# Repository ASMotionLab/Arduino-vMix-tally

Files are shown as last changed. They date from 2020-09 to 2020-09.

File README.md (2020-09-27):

# Arduino vMix tally

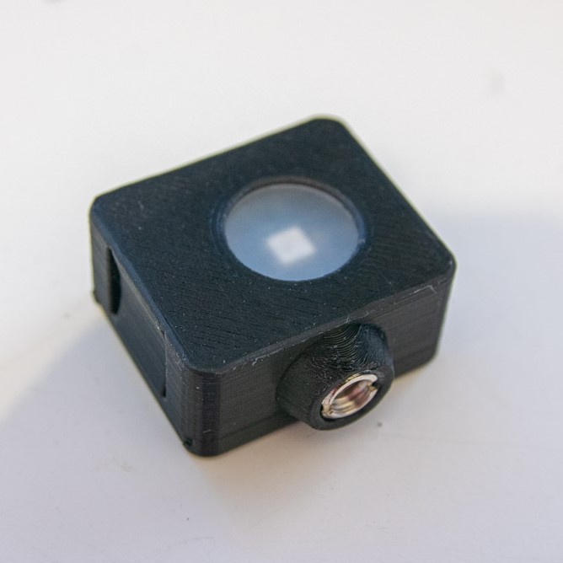
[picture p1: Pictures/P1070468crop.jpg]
Image of Tally


This project contains the firmware for a tally system based on an Arduino esp8266 and the vMix TCP API. 
Pictures of the tally can be found in the Pictures folder.

This fork adapts the existing project by Thomas Mout to work with a single WS2812B (Neopixel) led shield instead of the original LED matrix shield. Multiple WS2812B leds will also work.

There are modifications to change LED brightness from the setup web page, and a factory reset button to load defaults.

Also added is a checkbox for enabling/disabling the green colour (the Preview colour of vMix).
This indicator may not be wanted if pointing tallys at the talent.

The enclosure has also been redesigned to fit the dev board + shield, to retain it, to allow mounting to a 1/4 tripod screw via a 3/8 adaptor boss.

## Installation

### Hardware

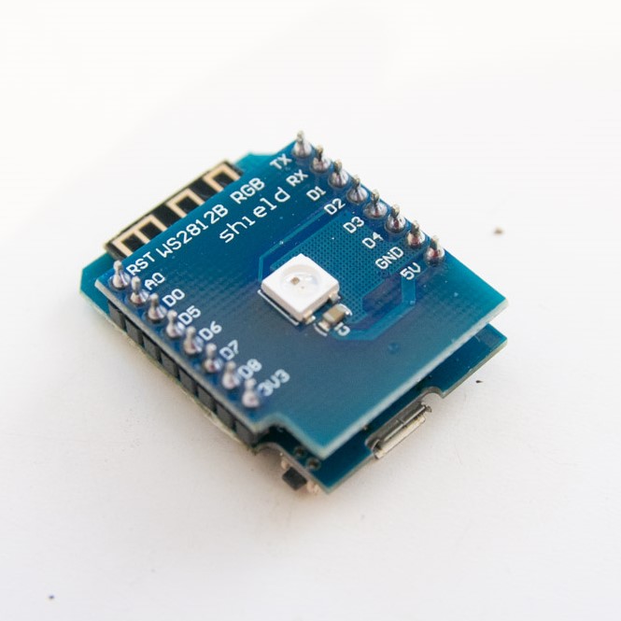
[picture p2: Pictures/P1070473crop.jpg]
Image of shield


This fork uses a WeMos/Lolin D1 Mini clone
https://www.banggood.com/Geekcreit-D1-mini-V2_2_0-WIFI-Internet-Development-Board-Based-ESP8266-4MB-FLASH-ESP-12S-Chip-p-1143874.html

and a WS2812B (Neopixel) shield.
https://www.amazon.co.uk/ILS-WS2812B-RGB-Shield-Mini/dp/B079128452

The 2 are soldered together, leaving clearance the thickness of a stanley blade between the D1 mini and the shield.

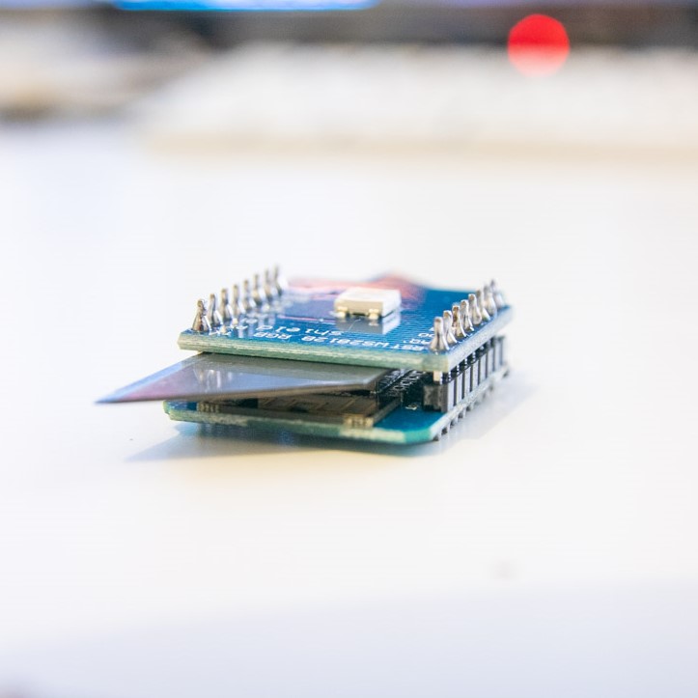
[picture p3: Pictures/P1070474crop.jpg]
Image of clearance


The 3d printable enclosure is designed to retain this board sandwich with a tight tolerance.

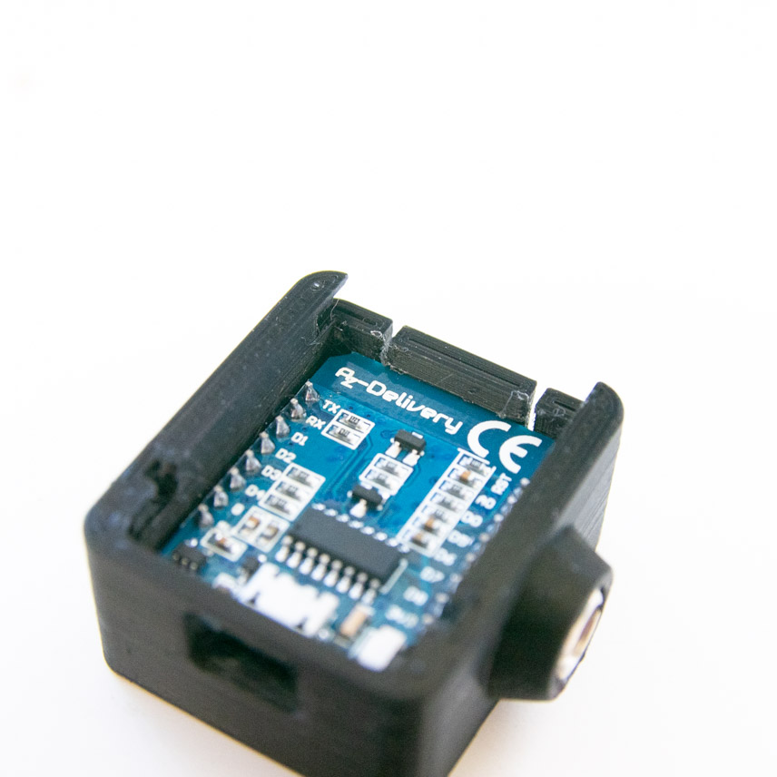
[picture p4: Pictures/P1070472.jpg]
Image of retention


The 'lens' used to diffuse the led is a 2cm diameter frosted acrylic circle (3mm thickness). It should press into the case if your printer is accurately calibrated.

#### Solder instructions

Make sure to match the board orientation when soldering the D1 and shield - make sure 3v3 goes to 3v3, 5v to 5v, etc etc.

### Software

#### 1. Install Arduino IDE

Download the Arduino IDE from the [Arduino website](https://www.arduino.cc/en/main/software) and install it.  
After the installation is complete go to File > Preferences and add http://arduino.esp8266.com/stable/package_esp8266com_index.json to the additional Board Manager URL.
Go to Tools > Board > Board Manager, search for *esp8266* and install the latest version.
After the installation go to Tools > Board and select *Wemos D1 R2* as your default board.  

#### 2. Copy libraries

All libraries included in the Libaries folder are required for this project. Please copy them to your own Arduino libraries folder (default path: *user/documents/Arduino/libraries*).
If some components are missing, you can easily find what's missing by googling the error.

#### 3. Uploading static files

Connect the Arduino to the computer with a USB cable.  
The static files in the Arduino-vMix-Tally/data folder must be uploaded using the Tools > ESP8266 Sketch Data Upload in the Arduino IDE.  

#### 4. Uploading firmware

Upload the Arduino-vMix-Tally/Arduino-vMix-Tally.ino from this repository to the D1 mini

#### 5. Connecting to your wireless network

To start with, the tally will try to connect to a non existent wifi network and will fail. After it fails, it becomes a wifi access point.
You can connect directly to it. It'll be called "vMix_Tally_X" where X is a number. The WiFi password is the same name, with "_access" added to the end._
So If the Access Point name is vMix_Tally_255, the password will be vMix_Tally_255_access.

Once you connect to it, navigate to address 192.168.4.1 in the browser.
You may find that there are strange characters in the entry fields. This is because the memory locations where this data are stored on the D1 may not be clear.
You can do a factory reset and come back to the page, or just delete all the strangeness and set up the fields to suit your network.

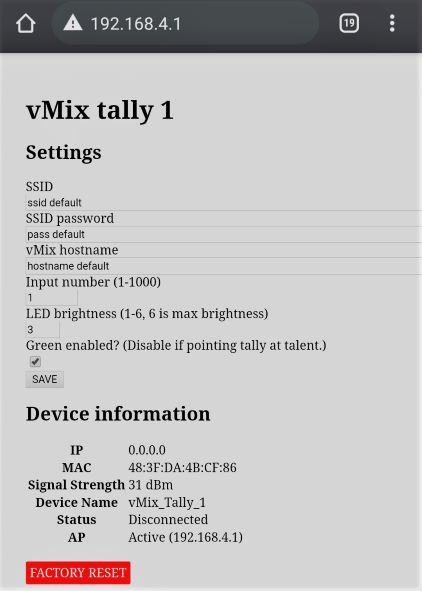
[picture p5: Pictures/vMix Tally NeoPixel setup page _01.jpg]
Image of ap setup


Hit Save. Tally restarts.

#### 5. Connecting to vMix

If all the details are right and vMix is running, it should light up blue and after 5-30s either turn off, go green or red.
vMix API runs on port 8099, so this port needs to be reachable by the tally - make sure firewall isn't blocking it.

#### 6. Colours

BLUE light indicates the tally is trying to connect to a network, or it's an Access Point of it's own.

OFF means the camera is not being previewed and it's not live (but vMix connection is working).

GREEN means the camera is being previewed (vMix connection is working).

RED means the camera is LIVE (vMix connection is working).

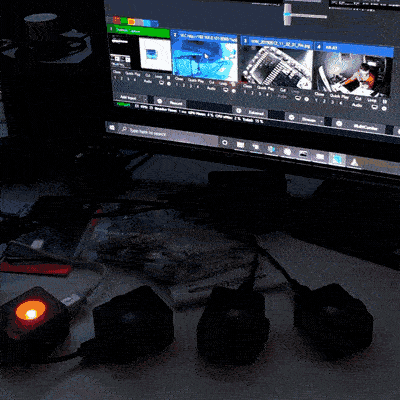
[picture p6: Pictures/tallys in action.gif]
Tallys in action


## Things to keep in mind

1. Make sure to use a power cable that does not support data when using a USB port on a camera. This can cause connecting issues in the camera.  
2. The D1 mini is completely dependent on a good WiFi signal.  
3. The tally must be connected to the same network as the vMix instance.
4. If you're having trouble setting up the tally, open a serial monitor with baud 9600 on the tally's COM port it will give you information about what it's doing.

## Footnote

Please note all images are for illustration purpose. Actual results may vary.  
Feel free open issues on this repository for bugs or feature requests.  
If you want to create your own version of this repository then a reference is appreciated.

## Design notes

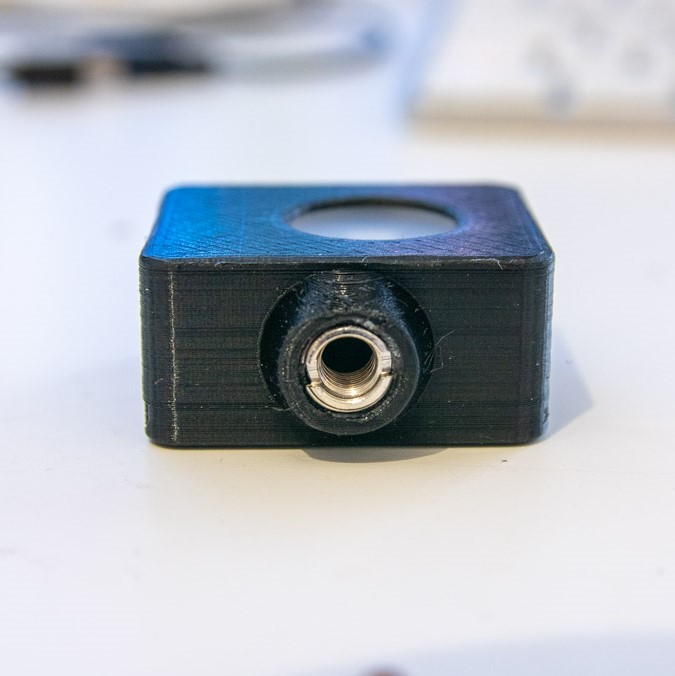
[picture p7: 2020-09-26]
Pictures/P1070469crop.jpg

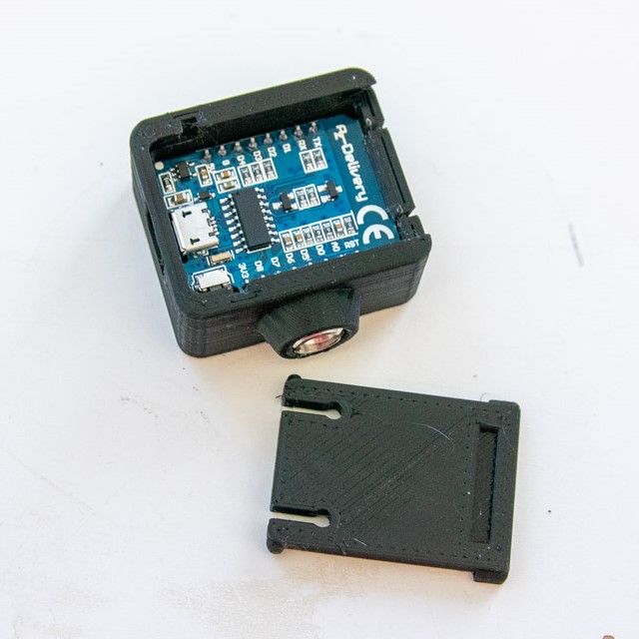
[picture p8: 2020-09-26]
Pictures/P1070471crop.jpg

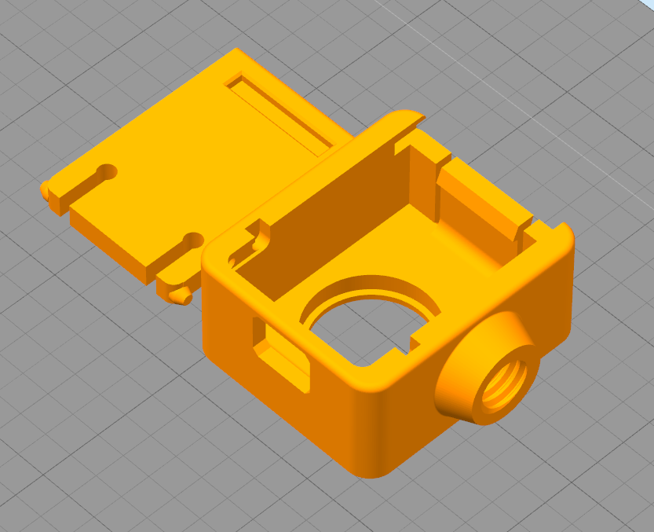
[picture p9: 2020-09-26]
Pictures/vMix Tally case and lid.PNG

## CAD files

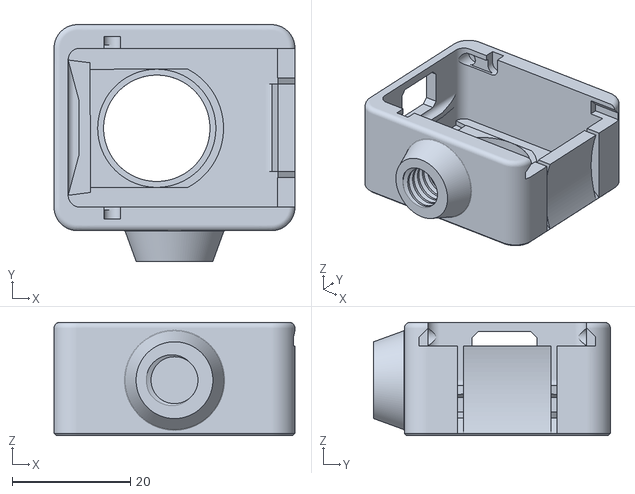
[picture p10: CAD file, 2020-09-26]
Case/VMixTallyV2_005.stl
40.8 x 40.1 x 19.2

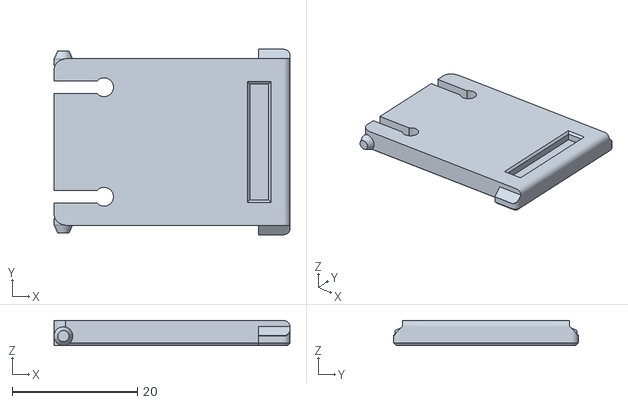
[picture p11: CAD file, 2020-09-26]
Case/VMixTallyV2_lid_002.stl
37.7 x 29.6 x 4.00

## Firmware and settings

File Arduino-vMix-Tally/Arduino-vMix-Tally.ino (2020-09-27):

/*
  vMix wireless tally
  Copyright 2019 Thomas Mout

  Modified by ASMotionLab on 25/09/2020
  LED Matrix code removed & adapted for the single neopixel (WS2812b) shield. Will work for any number of neopixels,
  just change LED_NUM.
  Added a brightness setting in the struct (1 to 6), 3 is default.
  Also added the setting into the web setup page

  Added a FACTORY RESET button into the web setup page, to reset settings to default
  
  27-09-2020 Update:
  Added a checkbox into the settings page, to enable/disable the green (vMix preview) led.
  For example you may want to disable it when pointing tallys at the talent, where green (vMix preview) is not wanted.
*/

#include <EEPROM.h>
#include <ESP8266WiFi.h>
#include <ESP8266WebServer.h>
#include <WiFiClient.h>
#include <Adafruit_GFX.h>
#include "FS.h"
#include <Adafruit_NeoPixel.h>

// Constants
const int SsidMaxLength = 64;
const int PassMaxLength = 64;
const int HostNameMaxLength = 64;
const int TallyNumberMaxValue = 64;
const int LEDBrightnessMaxValue = 6;


// Settings object
struct Settings
{
  char ssid[SsidMaxLength];
  char pass[PassMaxLength];
  char hostName[HostNameMaxLength];
  int tallyNumber;
  int ledBrightness;
  bool greenEnabled;
};

// Default settings object
Settings defaultSettings = {
  "ssid default",
  "pass default",
  "hostname default",
  1,
  3,
  1
};

Settings settings;

// HTTP Server settings
ESP8266WebServer httpServer(80);
char deviceName[32];
int status = WL_IDLE_STATUS;
bool apEnabled = false;
char apPass[64];

// vMix settings
int port = 8099;

// Tally info
char currentState = -1;
const char tallyStateOff = 0;
const char tallyStateProgram = 1;
const char tallyStatePreview = 2;

// The WiFi client
WiFiClient client;
int timeout = 10;
int delayTime = 10000;

// Time measure
int interval = 5000;
unsigned long lastCheck = 0;

// Neopixel WS2812b settings
#define NEOPIXEL_PIN   D2
#define LED_NUM 1
Adafruit_NeoPixel leds = Adafruit_NeoPixel(LED_NUM, NEOPIXEL_PIN, NEO_GRB + NEO_KHZ800);

// Load settings from EEPROM
void loadSettings()
{
  Serial.println("------------");
  Serial.println("Loading settings");

  long ptr = 0;

  for (int i = 0; i < SsidMaxLength; i++)
  {
    settings.ssid[i] = EEPROM.read(ptr);
    ptr++;
  }

  for (int i = 0; i < PassMaxLength; i++)
  {
    settings.pass[i] = EEPROM.read(ptr);
    ptr++;
  }

  for (int i = 0; i < HostNameMaxLength; i++)
  {
    settings.hostName[i] = EEPROM.read(ptr);
    ptr++;
  }

  settings.tallyNumber = EEPROM.read(ptr);

  ptr++;

  settings.ledBrightness = EEPROM.read(ptr);

  ptr++;

  settings.greenEnabled = EEPROM.read(ptr);

  if (strlen(settings.ssid) == 0 || strlen(settings.pass) == 0 || strlen(settings.hostName) == 0 || settings.tallyNumber == 0 || settings.ledBrightness == 0)
  {
    Serial.println("No settings found");
    Serial.println("Loading default settings");
    settings = defaultSettings;
    saveSettings();
    restart();
  }
  else
  {
    Serial.println("Settings loaded");
    printSettings();
    Serial.println("------------");
  }
  
  ledSetIntensity(settings.ledBrightness);
}

// Save settings to EEPROM
void saveSettings()
{
  Serial.println("------------");
  Serial.println("Saving settings");

  long ptr = 0;

  for (int i = 0; i < 512; i++)
  {
    EEPROM.write(i, 0);
  }

  for (int i = 0; i < SsidMaxLength; i++)
  {
    EEPROM.write(ptr, settings.ssid[i]);
    ptr++;
  }

  for (int i = 0; i < PassMaxLength; i++)
  {
    EEPROM.write(ptr, settings.pass[i]);
    ptr++;
  }

  for (int i = 0; i < HostNameMaxLength; i++)
  {
    EEPROM.write(ptr, settings.hostName[i]);
    ptr++;
  }

  EEPROM.write(ptr, settings.tallyNumber);

  ptr++;

  EEPROM.write(ptr, settings.ledBrightness);

  ptr++;

  EEPROM.write(ptr, settings.greenEnabled);

  EEPROM.commit();

  Serial.println("Settings saved");
  printSettings();
  Serial.println("------------");

  ledSetIntensity(settings.ledBrightness);
}

// Print settings
void printSettings()
{
  Serial.println();
  Serial.print("SSID: ");
  Serial.println(settings.ssid);
  Serial.print("SSID Password: ");
  Serial.println(settings.pass);
  Serial.print("vMix hostname: ");
  Serial.println(settings.hostName);
  Serial.print("Tally number: ");
  Serial.println(settings.tallyNumber);
  Serial.print("LED brightness: ");
  Serial.println(settings.ledBrightness);
  Serial.print("Green enabled: ");
  Serial.println(settings.greenEnabled);
  
}

// Set led intensity from 1 to 6
void ledSetIntensity(int intensity)
{
//  matrix.intensity = intensity;
  leds.setBrightness(map(intensity,1,6,20,255));
  
}

// Set LED's off
void ledSetOff()
{
  led_set(0, 0, 0);//red
}

// Draw L(ive) with LED's
void ledSetProgram()
{
  led_set(255, 0, 0);//off
}

// Draw P(review) with LED's
void ledSetPreview()
{
  if (settings.greenEnabled) {
    led_set(0, 255, 0);//green
  } else {
    led_set(0, 0, 0);//off
  }
}

// Draw C(onnecting) with LED's
void ledSetConnecting()
{
  led_set(0, 0, 255);//blue
}

// Draw S(ettings) with LED's
void ledSetSettings()
{
  ;
}

// Set tally to off
void tallySetOff()
{
  Serial.println("Tally off");

  ledSetOff();
}

// Set tally to program
void tallySetProgram()
{
  Serial.println("Tally program");

  ledSetOff();
  ledSetProgram();
}

// Set tally to preview
void tallySetPreview()
{
  Serial.println("Tally preview");

  ledSetOff();
  ledSetPreview();
}

// Set tally to connecting
void tallySetConnecting()
{
  ledSetOff();
  ledSetConnecting();
}

// Handle incoming data
void handleData(String data)
{
  // Check if server data is tally data
  if (data.indexOf("TALLY") == 0)
  {
    char newState = data.charAt(settings.tallyNumber + 8);

    // Check if tally state has changed
    if (currentState != newState)
    {
      currentState = newState;

      switch (currentState)
      {
        case '0':
          tallySetOff();
          break;
        case '1':
          tallySetProgram();
          break;
        case '2':
          tallySetPreview();
          break;
        default:
          tallySetOff();
      }
    }
  }
  else
  {
    Serial.print("Response from vMix: ");
    Serial.println(data);
  }
}

// Start access point
void apStart()
{
  ledSetSettings();
  Serial.println("AP Start");
  Serial.print("AP SSID: ");
  Serial.println(deviceName);
  Serial.print("AP password: ");
  Serial.println(apPass);

  WiFi.mode(WIFI_AP);
  WiFi.hostname(deviceName);
  WiFi.softAP(deviceName, apPass);
  delay(100);
  IPAddress myIP = WiFi.softAPIP();
  Serial.print("IP address: ");
  Serial.println(myIP);

  apEnabled = true;
}

// Hanle http server root request
void rootPageHandler()
{
  String response_message = "<!DOCTYPE html>";
  response_message += "<html lang='en'>";
  response_message += "<head>";
  response_message += "<title>" + String(deviceName) + "</title>";
  response_message += "<meta name='viewport' content='width=device-width, initial-scale=1, shrink-to-fit=no'>";
  response_message += "<meta charset='utf-8'>";
  response_message += "<link rel='icon' type='image/x-icon' href='favicon.ico'>";
  response_message += "<link rel='stylesheet' href='styles.css'>";
  response_message += "<style>body {width: 100%;height: 100%;padding: 25px;}";
  response_message += ".button {display: inline-block;background-color: #FF0000;border: none;color: white;padding: 5px 5px;text-decoration: none;margin: 0px auto 10px;cursor: pointer;border-radius: 2px;}</style>";
  response_message += "</head>";

  response_message += "<body class='bg-light'>";

  response_message += "<h1>vMix tally " + String(settings.tallyNumber) + "</h1>";
  response_message += "<div data-role='content' class='row'>";

  response_message += "<div class='col-md-6'>";
  response_message += "<h2>Settings</h2>";
  response_message += "<form action='/save' method='post' enctype='multipart/form-data' data-ajax='false'>";

  response_message += "<div class='form-group row'>";
  response_message += "<label for='ssid' class='col-sm-4 col-form-label'>SSID</label>";
  response_message += "<div class='col-sm-8'>";
  response_message += "<input id='ssid' class='form-control' type='text' size='64' maxlength='64' name='ssid' value='" + String(settings.ssid) + "'>";
  response_message += "</div></div>";

  response_message += "<div class='form-group row'>";
  response_message += "<label for='ssidpass' class='col-sm-4 col-form-label'>SSID password</label>";
  response_message += "<div class='col-sm-8'>";
  response_message += "<input id='ssidpass' class='form-control' type='text' size='64' maxlength='64' name='ssidpass' value='" + String(settings.pass) + "'>";
  response_message += "</div></div>";

  response_message += "<div class='form-group row'>";
  response_message += "<label for='hostname' class='col-sm-4 col-form-label'>vMix hostname</label>";
  response_message += "<div class='col-sm-8'>";
  response_message += "<input id='hostname' class='form-control' type='text' size='64' maxlength='64' name='hostname' value='" + String(settings.hostName) + "'>";
  response_message += "</div></div>";

  response_message += "<div class='form-group row'>";
  response_message += "<label for='inputnumber' class='col-sm-4 col-form-label'>Input number (1-1000)</label>";
  response_message += "<div class='col-sm-8'>";
  response_message += "<input id='inputnumber' class='form-control' type='number' size='64' min='0' max='1000' name='inputnumber' value='" + String(settings.tallyNumber) + "'>";
  response_message += "</div></div>";
  
  response_message += "<div class='form-group row'>";
  response_message += "<label for='inputnumber2' class='col-sm-4 col-form-label'>LED brightness (1-6, 6 is max brightness)</label>";
  
  response_message += "<div class='col-sm-8'>";
  response_message += "<input id='inputnumber2' class='form-control' type='number' size='64' min='1' max='6' name='inputnumber2' value='" + String(settings.ledBrightness) + "'>";
  response_message += "</div></div>";

  response_message += "<div class='form-group row'>";
  response_message += "<label for='checkbox1' class='col-sm-4 col-form-label'>Green enabled? (Disable if pointing tally at talent.)</label>";

  response_message += "<div class='col-sm-8'>";
  if (settings.greenEnabled) {
    response_message += "<input id='checkbox1' class='form-control' type='checkbox' name='checkbox1' checked value='" + String(settings.greenEnabled) + "'>";
  } else {
    response_message += "<input id='checkbox1' class='form-control' type='checkbox' name='checkbox1' value='" + String(settings.greenEnabled) + "'>";
  }

  response_message += "</div></div>";

  response_message += "<input type='submit' value='SAVE' class='btn btn-primary'></form>";
  response_message += "</div>";

  response_message += "<div class='col-md-6'>";
  response_message += "<h2>Device information</h2>";
  response_message += "<table class='table'><tbody>";

  char ip[13];
  sprintf(ip, "%d.%d.%d.%d", WiFi.localIP()[0], WiFi.localIP()[1], WiFi.localIP()[2], WiFi.localIP()[3]);
  response_message += "<tr><th>IP</th><td>" + String(ip) + "</td></tr>";

  response_message += "<tr><th>MAC</th><td>" + String(WiFi.macAddress()) + "</td></tr>";
  response_message += "<tr><th>Signal Strength</th><td>" + String(WiFi.RSSI()) + " dBm</td></tr>";
  response_message += "<tr><th>Device Name</th><td>" + String(deviceName) + "</td></tr>";

  if (WiFi.status() == WL_CONNECTED)
  {
    response_message += "<tr><th>Status</th><td>Connected</td></tr>";
  }
  else
  {
    response_message += "<tr><th>Status</th><td>Disconnected</td></tr>";
  }

  if (apEnabled)
  {
    sprintf(ip, "%d.%d.%d.%d", WiFi.softAPIP()[0], WiFi.softAPIP()[1], WiFi.softAPIP()[2], WiFi.softAPIP()[3]);
    response_message += "<tr><th>AP</th><td>Active (" + String(ip) + ")</td></tr>";
  }
  else
  {
    response_message += "<tr><th>AP</th><td>Inactive</td></tr>";
  }
  response_message += "</tbody></table>";
  
  response_message += "<div class='col-md-6'>";
     
  response_message += "<br>";

  response_message += "<a class=\"button button-factoryreset\" href=\"/factoryreset\">FACTORY RESET</a>";
  
  response_message += "</div>";
  
  response_message += "</div>";
  response_message += "</div>";

  response_message += "</body>";
  response_message += "</html>";

  httpServer.sendHeader("Connection", "close");
  httpServer.send(200, "text/html", String(response_message));
}

// Settings POST handler
void handleSave()
{
  bool doRestart = false;

  httpServer.sendHeader("Location", String("/"), true);
  httpServer.send(302, "text/plain", "Redirected to: /");

  if (httpServer.hasArg("ssid"))
  {
    if (httpServer.arg("ssid").length() <= SsidMaxLength)
    {
      httpServer.arg("ssid").toCharArray(settings.ssid, SsidMaxLength);
      doRestart = true;
    }
  }

  if (httpServer.hasArg("ssidpass"))
  {
    if (httpServer.arg("ssidpass").length() <= PassMaxLength)
    {
      httpServer.arg("ssidpass").toCharArray(settings.pass, PassMaxLength);
      doRestart = true;
    }
  }

  if (httpServer.hasArg("hostname"))
  {
    if (httpServer.arg("hostname").length() <= HostNameMaxLength)
    {
      httpServer.arg("hostname").toCharArray(settings.hostName, HostNameMaxLength);
      doRestart = true;
    }
  }

  if (httpServer.hasArg("inputnumber"))
  {
    if (httpServer.arg("inputnumber").toInt() > 0 and httpServer.arg("inputnumber").toInt() <= TallyNumberMaxValue)
    {
      settings.tallyNumber = httpServer.arg("inputnumber").toInt();
      doRestart = true;
    }
  }

  if (httpServer.hasArg("inputnumber2"))
  {
    if (httpServer.arg("inputnumber2").toInt() > 0 and httpServer.arg("inputnumber2").toInt() <= LEDBrightnessMaxValue)
    {
      settings.ledBrightness = httpServer.arg("inputnumber2").toInt();
      doRestart = true;
    }
  }

  if (httpServer.hasArg("checkbox1"))
  {
      settings.greenEnabled = true;
      doRestart = true;
  } else {
      settings.greenEnabled = false;
      doRestart = true;
  }

  if (doRestart == true)
  {
    restart();
  }
}

void handlerFactoryReset()
{
  bool doRestart = false;

  httpServer.sendHeader("Location", String("/"), true);
  httpServer.send(302, "text/plain", "Redirected to: /");
  
  clearEeprom();
}

// Connect to WiFi
void connectToWifi()
{
  Serial.println();
  Serial.println("------------");
  Serial.println("Connecting to WiFi");
  Serial.print("SSID: ");
  Serial.println(settings.ssid);
  Serial.print("Passphrase: ");
  Serial.println(settings.pass);

  int timeout = 15;

  WiFi.mode(WIFI_STA);
  WiFi.hostname(deviceName);
  WiFi.begin(settings.ssid, settings.pass);

  Serial.print("Waiting for connection.");
  while (WiFi.status() != WL_CONNECTED and timeout > 0)
  {
    delay(1000);
    timeout--;
    Serial.print(".");
  }

  if (WiFi.status() == WL_CONNECTED)
  {
    Serial.println("Success!");
    Serial.print("IP address: ");
    Serial.println(WiFi.localIP());
    Serial.print("Device name: ");
    Serial.println(deviceName);
    Serial.println("------------");
  }
  else
  {
    if (WiFi.status() == WL_IDLE_STATUS)
      Serial.println("Idle");
    else if (WiFi.status() == WL_NO_SSID_AVAIL)
      Serial.println("No SSID Available");
    else if (WiFi.status() == WL_SCAN_COMPLETED)
      Serial.println("Scan Completed");
    else if (WiFi.status() == WL_CONNECT_FAILED)
      Serial.println("Connection Failed");
    else if (WiFi.status() == WL_CONNECTION_LOST)
      Serial.println("Connection Lost");
    else if (WiFi.status() == WL_DISCONNECTED)
      Serial.println("Disconnected");
    else
      Serial.println("Unknown Failure");

    Serial.println("------------");
    apStart();
  }
}

// Connect to vMix instance
void connectTovMix()
{
  Serial.print("Connecting to vMix on ");
  Serial.print(settings.hostName);
  Serial.print("...");

  if (client.connect(settings.hostName, port))
  {
    Serial.println(" Connected!");
    Serial.println("------------");
    
    tallySetOff();

    // Subscribe to the tally events
    client.println("SUBSCRIBE TALLY");
  }
  else
  {
    Serial.println(" Not found!");
  }
}

void restart()
{
  saveSettings();

  Serial.println();
  Serial.println();
  Serial.println("------------");
  Serial.println("------------");
  Serial.println("RESTART");
  Serial.println("------------");
  Serial.println("------------");
  Serial.println();
  Serial.println();

  start();
}

void start()
{
  tallySetConnecting();
  
  loadSettings();
  sprintf(deviceName, "vMix_Tally_%d", settings.tallyNumber);
  sprintf(apPass, "%s%s", deviceName, "_access");

  connectToWifi();

  if (WiFi.status() == WL_CONNECTED)
  {
    connectTovMix();
  }
}

void led_set(uint8 R, uint8 G, uint8 B) 
{
  for (int i = 0; i < LED_NUM; i++) 
  {
    leds.setPixelColor(i, leds.Color(R, G, B));
    leds.show();
  }
}

void setup()
{
  Serial.begin(9600);
  EEPROM.begin(512);

  delay(10);
  
  SPIFFS.begin();

  leds.begin(); // This initializes the NeoPixel library.

  httpServer.on("/", HTTP_GET, rootPageHandler);
  httpServer.on("/save", HTTP_POST, handleSave);
  httpServer.on("/factoryreset", handlerFactoryReset);
  httpServer.serveStatic("/", SPIFFS, "/", "max-age=315360000");
  httpServer.begin();

  start();
}

void loop()
{
  httpServer.handleClient();

  while (client.available())
  {
    String data = client.readStringUntil('\r\n');
    handleData(data);   
  }

  if (!client.connected() && !apEnabled && millis() > lastCheck + interval)
  {   
    tallySetConnecting();

    client.stop();

    connectTovMix();
    lastCheck = millis();
  }
}

void clearEeprom() {
  Serial.println("Clearing EEPROM");

  settings = defaultSettings;
  saveSettings();
  
  restart();
}
